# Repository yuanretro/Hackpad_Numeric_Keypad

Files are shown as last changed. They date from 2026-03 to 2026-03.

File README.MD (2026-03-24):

# HackPad: Numerical Keypad

By YuanRetro (William) Li, 2025.12 - 2026.3

Email: [admin@yuanshen.dev](mailto:admin@yuanshen.dev)

GitHub Repo: <https://github.com/yuanretro/Hackpad_Numeric_Keypad>

Last Revision: 2026-MAR-24

## Revision V4.0 2026-MAR-24

I edited the symbol in EasyEDA, so it now matches the diagram shown on SK6812 Mini-E's datasheet. This should solve the problem. 

The edit can be seen in the picture:

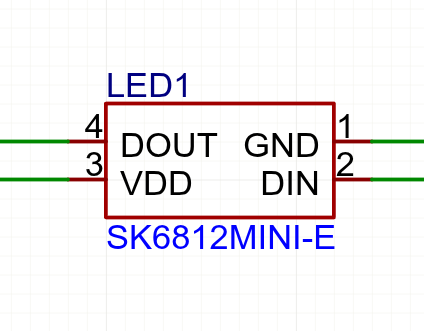
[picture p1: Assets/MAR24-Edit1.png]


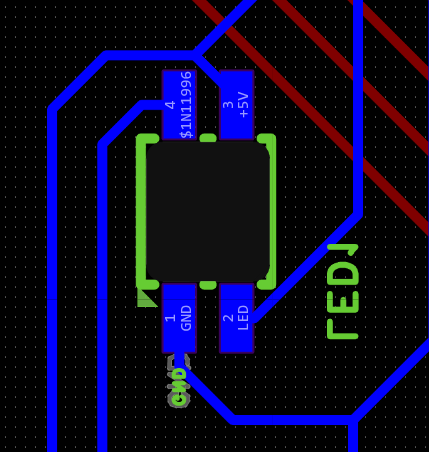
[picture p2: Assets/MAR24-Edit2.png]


## Revision V3.0 2026-MAR-23

I removed the button of the encoder from the matrix, and now the matrix is 4x4 instead of 5x4. The one extra GPIO is used to wire the encoder properly. Numlock can now be enabled by a long press of a certain key. The exact configuration is yet to be determined in the code. This edit also downsized the number of diodes required from 17 to 16.

## Revision V2.0 2026-MAR-22

The LED mounts are being relocated to the opposite side of the board and rewired. While I do know that the rotary encoder need one extra wire for proper directional detection, and I've thought of many ways to resolve this issue, including dropping the keypad to 15 keys. But to be honest, I believe that this would undermine the project's core purpose as a useful numerical keypad. Since the rotary encoder serves a secondary role in this application, not being able to detect the direction of rotation isn't really a big concern to me. Also, this can be compensated by allowing to flip the direction of the controls while pushing down the button during roration.

## Revision V1.0 2026-MAR-22

All issues stated are being dealt with. The keypad is downsized to 16 keys, and the push button of a rotary encoder replaces the NumLock key. As there isn't enough GPIO left for the encoder, I decided to only wire one output pin to the controller. This configuration only allows the detection of the distance of rotation and not the direction, but this can be partially resolved by detecting whether the switch is being pressed during rotation and alter the direction of the controls accordingly. (Don't worry about the one extra diode, I have spare components myself.)

The LEDs are being updated to the Mini-E variant of SK6812, and all diodes are now through-hole mount. Strangely enough, there seems to be some design issues with the package of the LEDs in EasyEDA. The slot region and the SMD pads are in minor conflict. This shouldn't affect anything despite of giving out nasty errors in the DRC check.

For the casing, I added 4 mounting holes on the corners, each measured around 2.8mm, allowing the screws to fit tightly inside the plastic and hold the two pieces together. An assembled view is also available down below.

The firmware haven't been updated, and I will do this step once the hardware part is complete.

## Introduction

This is my custom variant of [*HackPad*](https://github.com/hackclub/hackpad), an open-source keypad designed by *HackClub*. My project is loosely based on this, but I chose a different path for many elements of my design. Instead of only a few keys like the sample design, I incorporated a full-size computer numpad, very useful for small-size laptops that lack one. For many games I've played, especially simulation games like *Microsoft Flight Simulator* or *SimRail*, the numpad plays a crucial role in the controls, and it would be a pain to play them without one. 

For example, I used *EasyEDA* for the PCB design instead of *KiCAD*, as I have quite a lot of previous experience with it since I designed my first PCB back in 2023. It is also much easier to order PCBs right from the editor, and this makes the whole process less error-prone. I designed my 3D-printable shell initially with *Tinkercad*, but made use of *Autodesk Fusion* for the final touches. I have an Ender 3 V2 printer myself, and I will be able to print the whole casing myself. I am sure that the casing may not work on the first try, as I don't currently have the assembled PCB on hand. I will be able to do some minor tweaks once the PCB is up and running. Finally, instead of making use of the *QMK* firmware, I decided to write my own in C++ using the Arduino framework. I was able to compile it in the *PlatformIO* environment and export the .uf2 file, but I don't know if it works on the real hardware yet. This is also subject to minor changes.

I started working on this project in mid-December last year, but I was busy with school most of the time and almost forgot about it. This week, during March Break, I was able to pick it up and give it a finishing touch, and I hope the final product will work fine!

Honestly speaking, I think I am also much more confident with projects like this after I successfully completed the final performance task for my Computer Engineering course at school this January. For that project, called *Funnicator*, I designed a pair of text communication devices along with my partner, which use an ESP32-S3 microcontroller and sit in a custom 3D-printed case. Our teacher liked them. It was my first time designing 3D-printed items, and it helped me a lot when designing the case for my keypad, which is even more complicated.



## Schematics and PCB Design

As previously stated, I designed my PCB in EasyEDA. It is 10 cm by 10 cm exactly (this is somewhat important for minimizing the cost of the PCB, somehow), and I managed to fit a full-size arrangement of mechanical switches for a numpad. The keyboard matrix comes in a 4-row by 4-column arrangement, and takes up 8 GPIOs on the RP2040 microcontroller. Each individual switch is paired with a 1N4148 diode, to prevent current from flowing back and enable multiple keypresses at once. I used one extra GPIO for the 4 SK6812 LEDs forming a strip, and another one for one pin of the rotary encoder. The last two GPIOs went to the rotary encoder, which will act as an auxiliary control for my numpad.

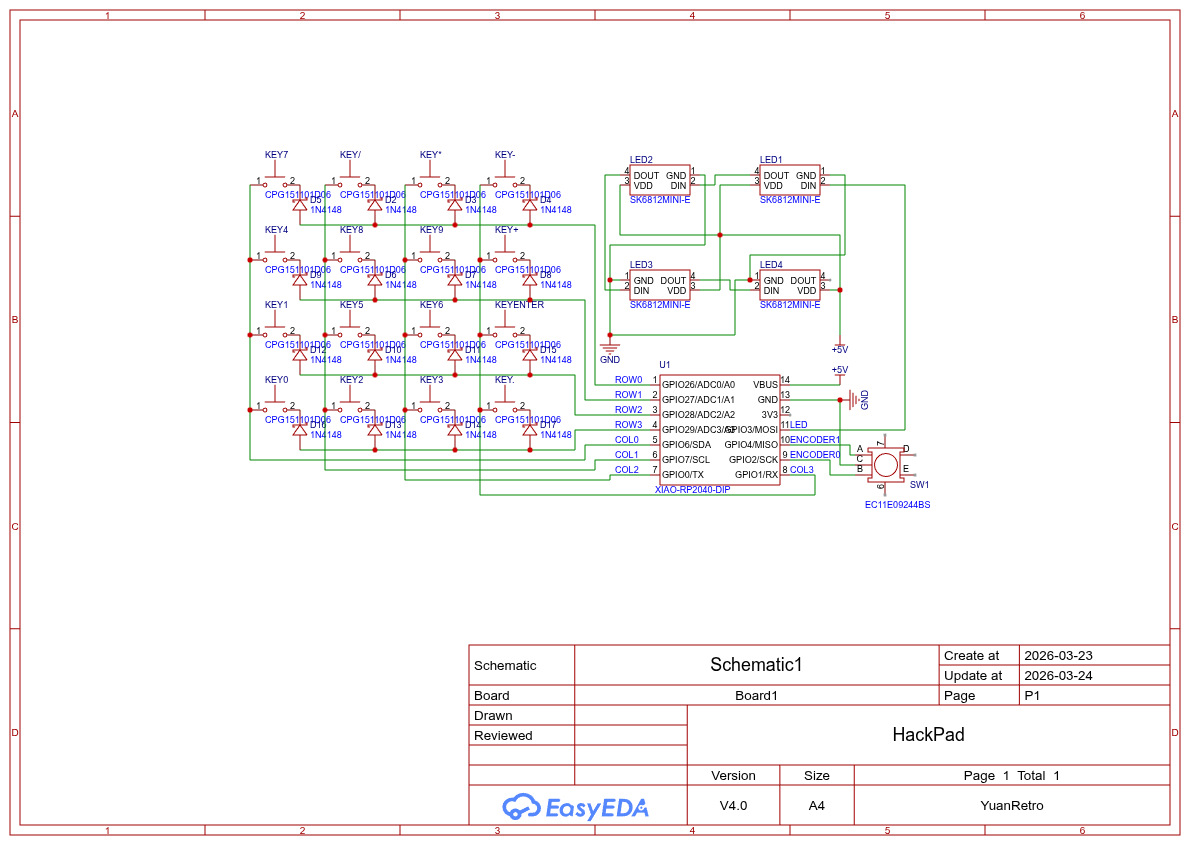
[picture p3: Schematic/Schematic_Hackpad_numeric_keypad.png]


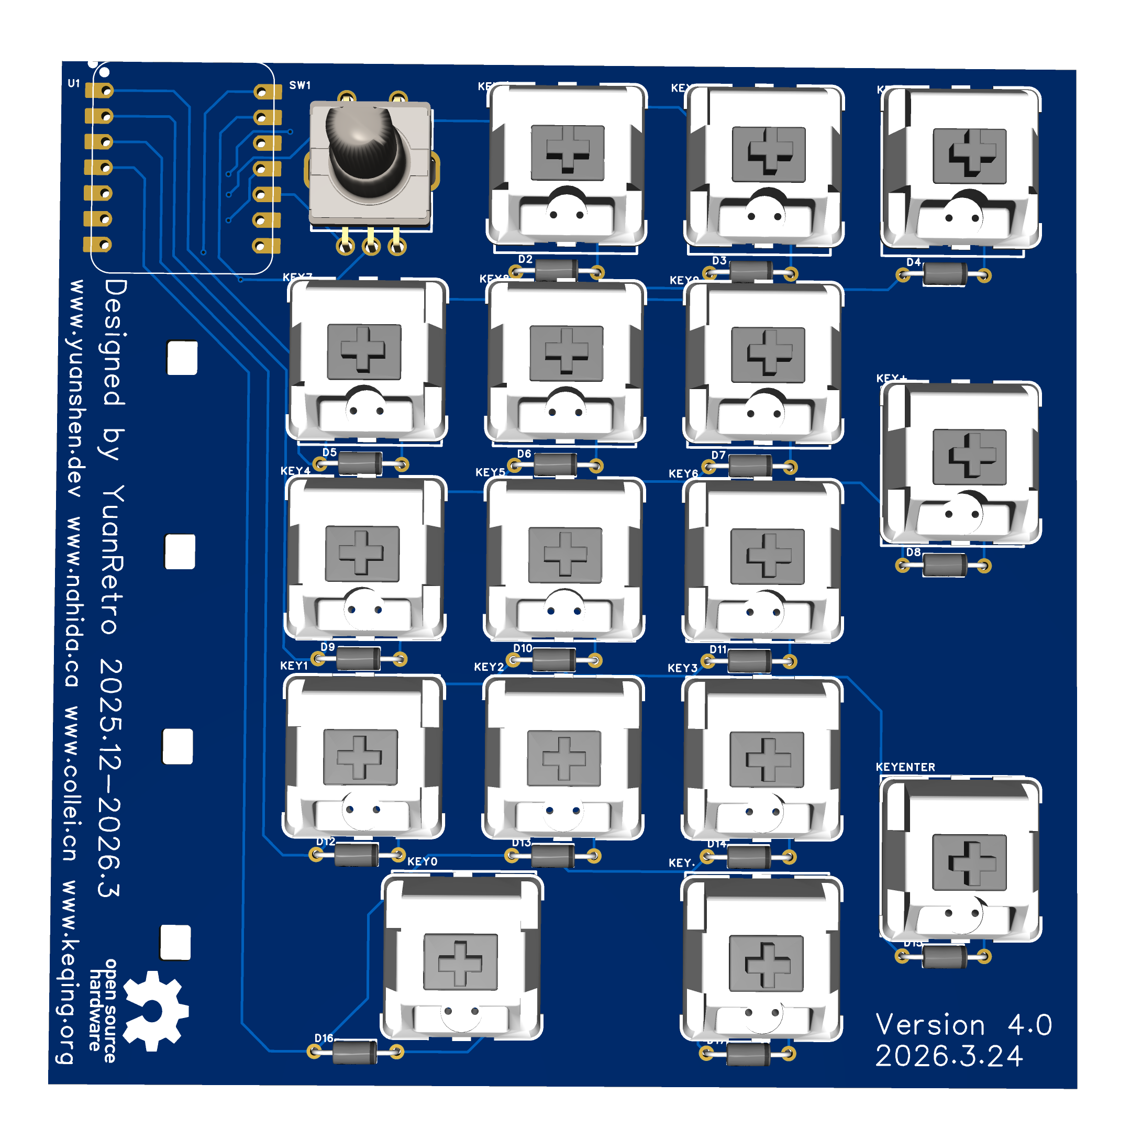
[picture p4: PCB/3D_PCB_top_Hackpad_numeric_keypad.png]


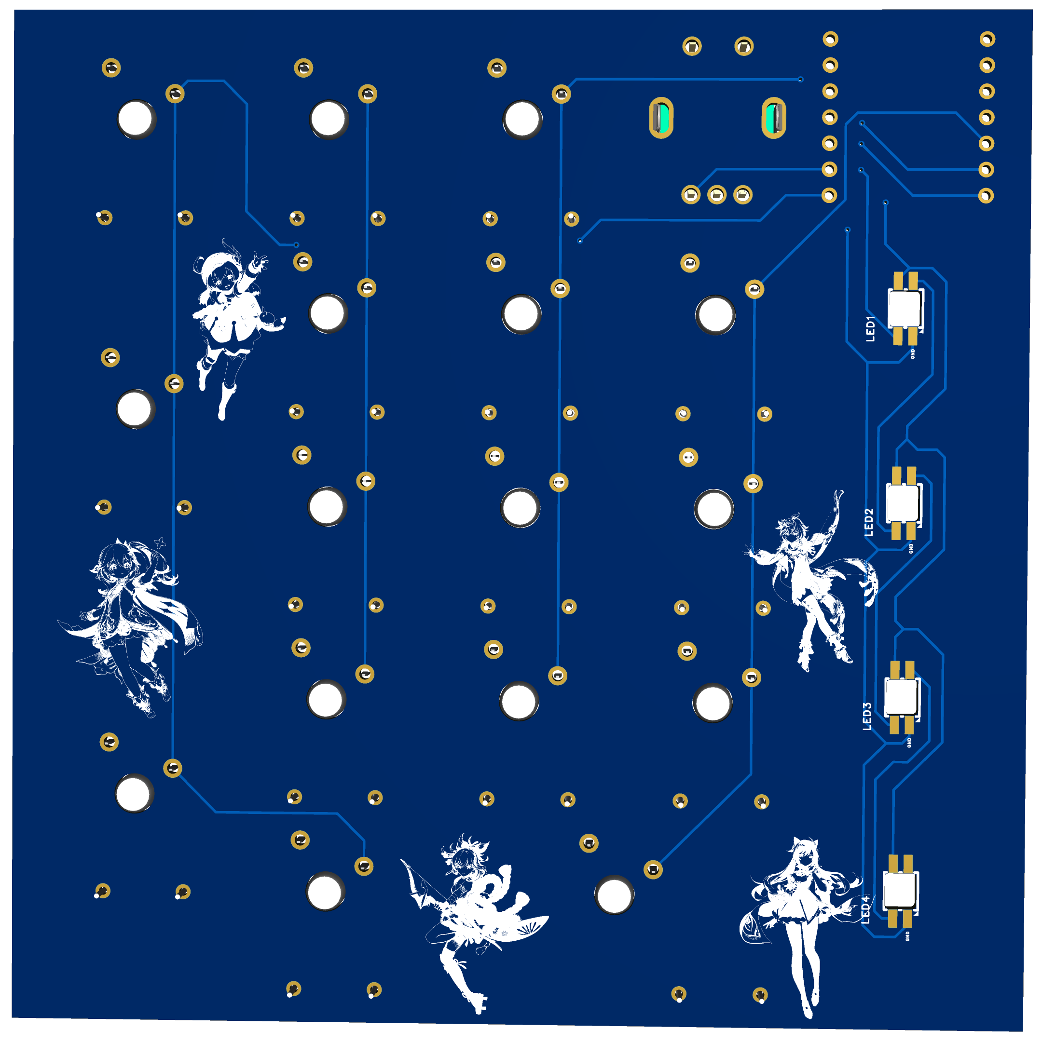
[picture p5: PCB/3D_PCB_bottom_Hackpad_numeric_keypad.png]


(clockwise from top-right: Collei, Keqing, Yoimiya, Nahida, and Klee)

## Parts Required

1 x Seeed Studio XIAO RP2040 Microcontroller

1 x EC11 Rotary Encoder

4 x SK6812 Mini-E Color LED

4 x M3 Screws of appropriate length (Supplied by myself)

16 x Standard Mechanical Key Switches

16 x Key Caps

16 x 1N4148 Diode

## Case Design

The case design is rather primitive, as I will definitely make some further tweaks once the PCB assembly is ready.  My idea for the casing is that it covers only the PCB and allows a small portion of the switch bodies to protrude above the case. This design can be found in many commercially available mechanical keyboards. It also comes with 4 2.8 mm mounting holes on the corners for screws to fit into.

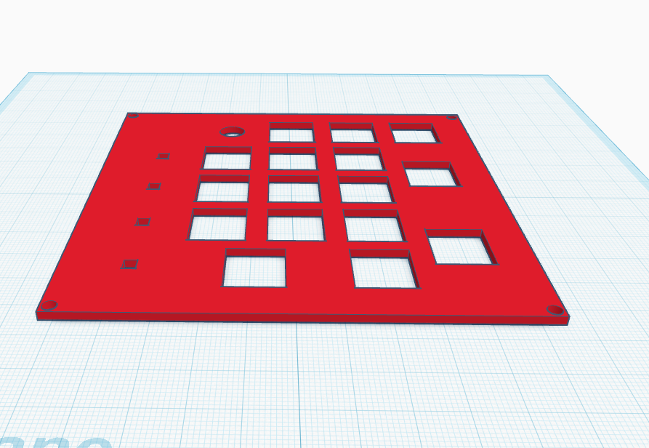
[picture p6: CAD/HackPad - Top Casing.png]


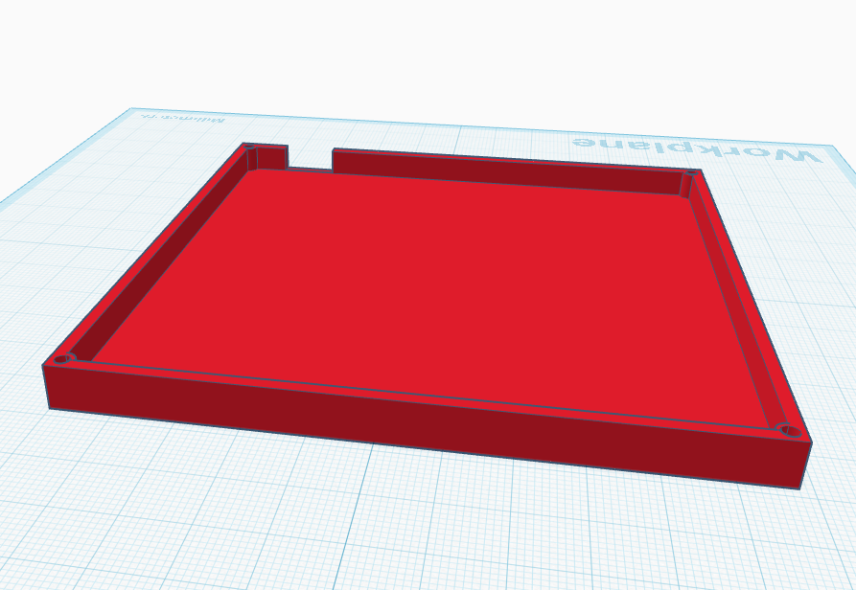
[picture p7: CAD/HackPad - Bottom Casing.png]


## Assembled View

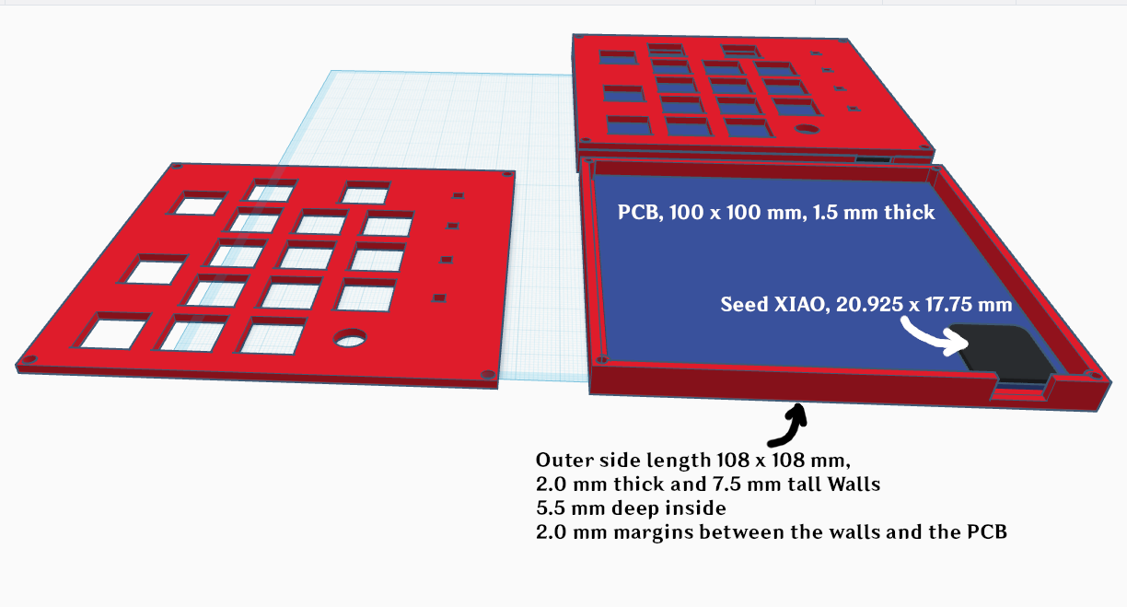
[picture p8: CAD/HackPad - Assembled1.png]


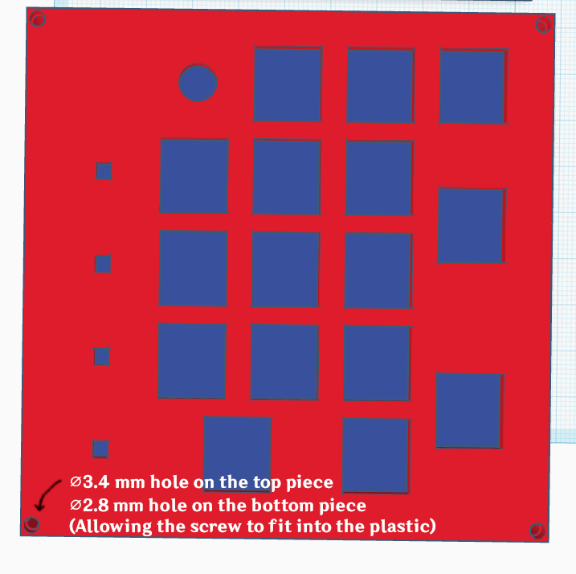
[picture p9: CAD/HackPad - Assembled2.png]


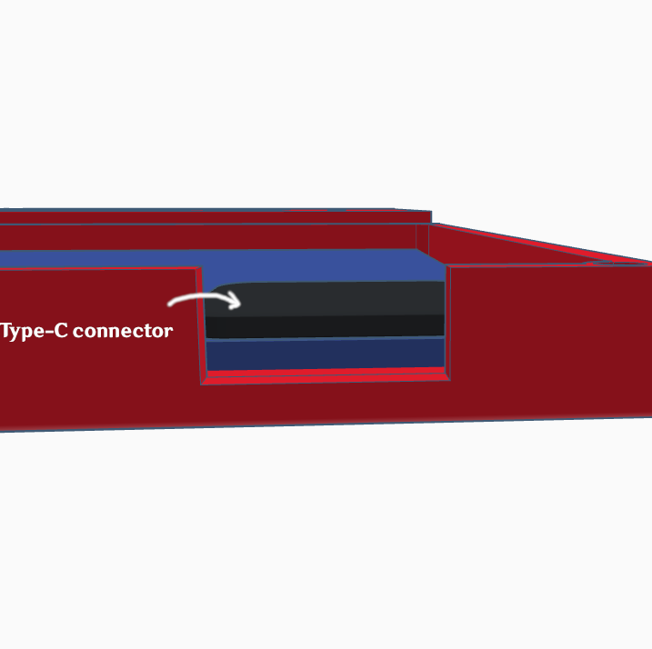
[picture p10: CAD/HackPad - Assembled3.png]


## Firmware

The firmware is written using the PlatformIO Arduino framework in C++. This can be changed at any time to fix bugs or add new features.

Current features of the firmware:

1. Registers the keypad as a standard USB HID device and sends inputs accordingly.

2. The NumLock key switches between number and function keys.

3. One of the LEDs in the strip indicates the current NumLock state, while the others flash on input.

4. The LED strip displays a breathing effect when the keypad is idle.

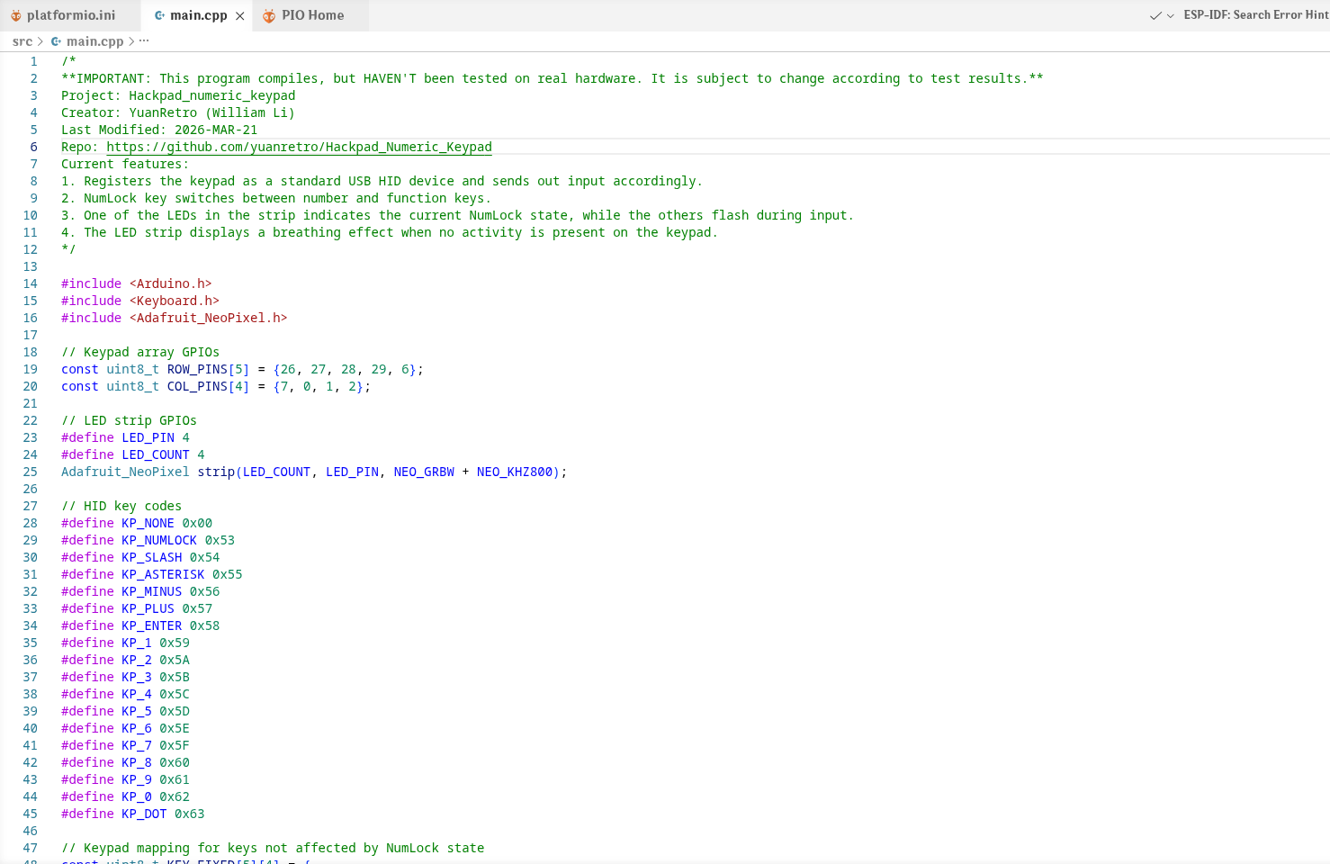
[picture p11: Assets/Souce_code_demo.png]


## Final Words

This project is rather novel to me, as it is my first time working with a RP2040 and USB HID devices. But it turned out easier than I originally thought it would be, and I hope it will work fine once everything is put together in the end!

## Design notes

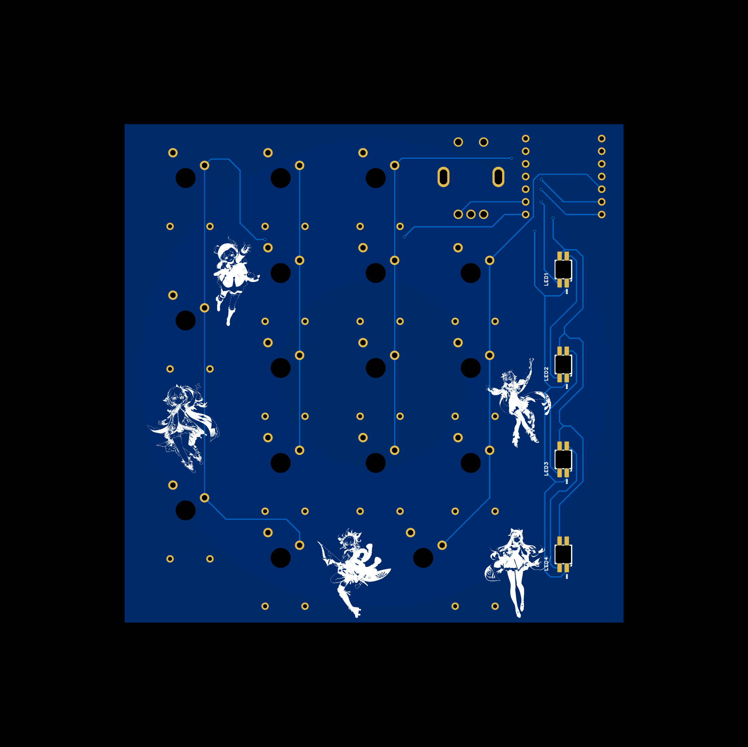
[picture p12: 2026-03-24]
PCB/2D_PCB_bottom_Hackpad_numeric_keypad.png

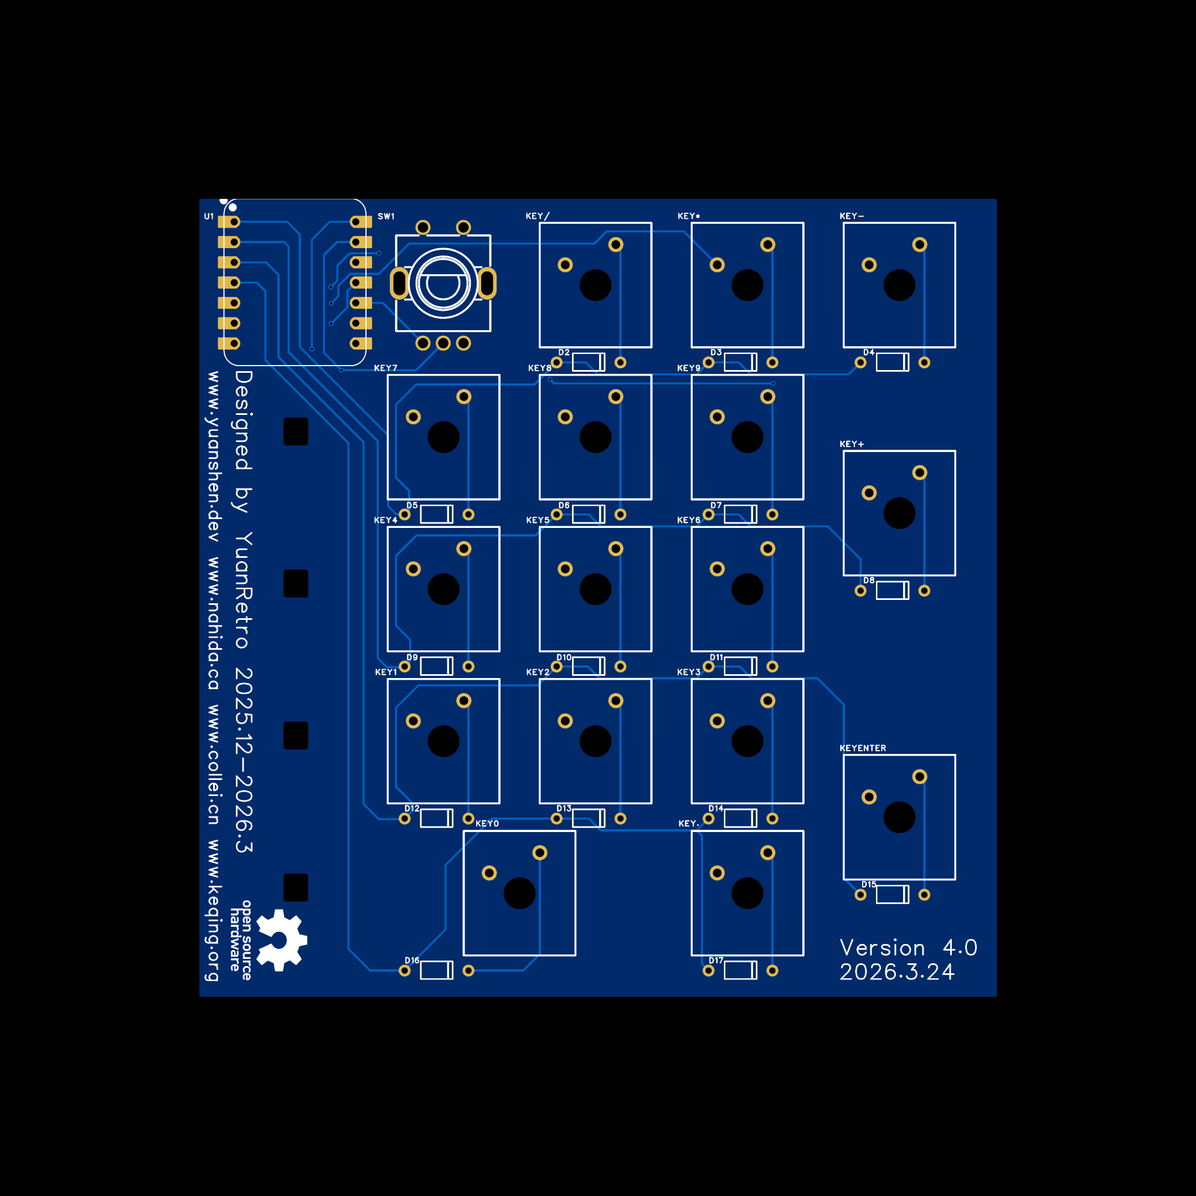
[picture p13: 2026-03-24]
PCB/2D_PCB_top_Hackpad_numeric_keypad.png

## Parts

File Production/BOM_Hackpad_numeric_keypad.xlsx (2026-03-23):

No. | Quantity | Comment | Designator | Footprint | Value | Manufacturer Part | Manufacturer | Supplier Part | Supplier
1 | 16 | 1N4148 | D2,D3,D4,D5,D6,D7,D8,D9,D10,D11,D12,D13,D14,D15,D16,D17 | DO-35_BD2.2-L4.0-D0.50_1N4148 |  | 1N4148 | LJ(朗捷) | C18195411 | LCSC
2 | 16 | CPG151101D06 | KEY0,KEY1,KEY2,KEY3,KEY4,KEY5,KEY6,KEY7,KEY8,KEY9,KEY*,KEY+,KEY-,KEY.,KEY/,KEYENTER | KEY-TH_CPG151101D06 |  | CPG151101D06 | HanElectricity(瀚源) | C49234237 | LCSC
3 | 4 | SK6812MINI-E | LED1,LED2,LED3,LED4 | LED-SMD_4P-L3.2-W2.8-LS5.9_SK6812MINI-E |  | SK6812MINI-E | 欧思科光电 | C5149201 | LCSC
4 | 1 | EC11E09244BS | SW1 | SW-TH_EC11XXXXXXXX |  | EC11E09244BS | ALPSALPINE(阿尔卑斯阿尔派) | C470742 | LCSC
5 | 1 | XIAO-RP2040-DIP | U1 | XIAO-RP2040-DIP

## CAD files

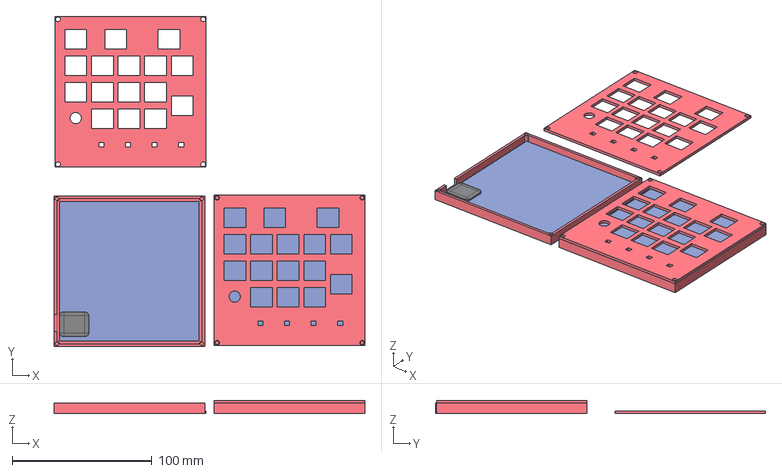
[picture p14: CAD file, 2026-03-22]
CAD/HackPad - Assembled.step
222.8 x 236.5 x 9.50 mm

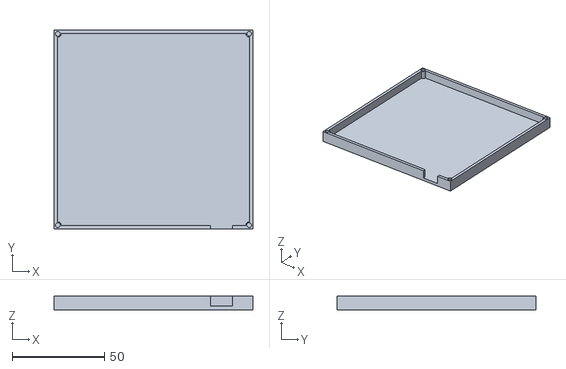
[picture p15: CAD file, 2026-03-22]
Production/Print_HackPad_Bottom Casing.stl
108.0 x 108.0 x 7.50

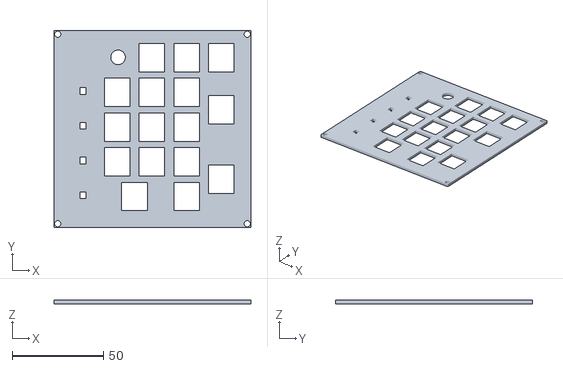
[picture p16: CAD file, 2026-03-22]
Production/Print_HackPad_Top Casing.stl
108.0 x 108.0 x 2.00

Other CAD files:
CAD/HackPad - Bottom Casing.step
CAD/HackPad - Top Casing.step
CAD/HackPad - Assembled.f3d
CAD/HackPad - Bottom Casing.f3d
CAD/HackPad - Top Casing.f3d

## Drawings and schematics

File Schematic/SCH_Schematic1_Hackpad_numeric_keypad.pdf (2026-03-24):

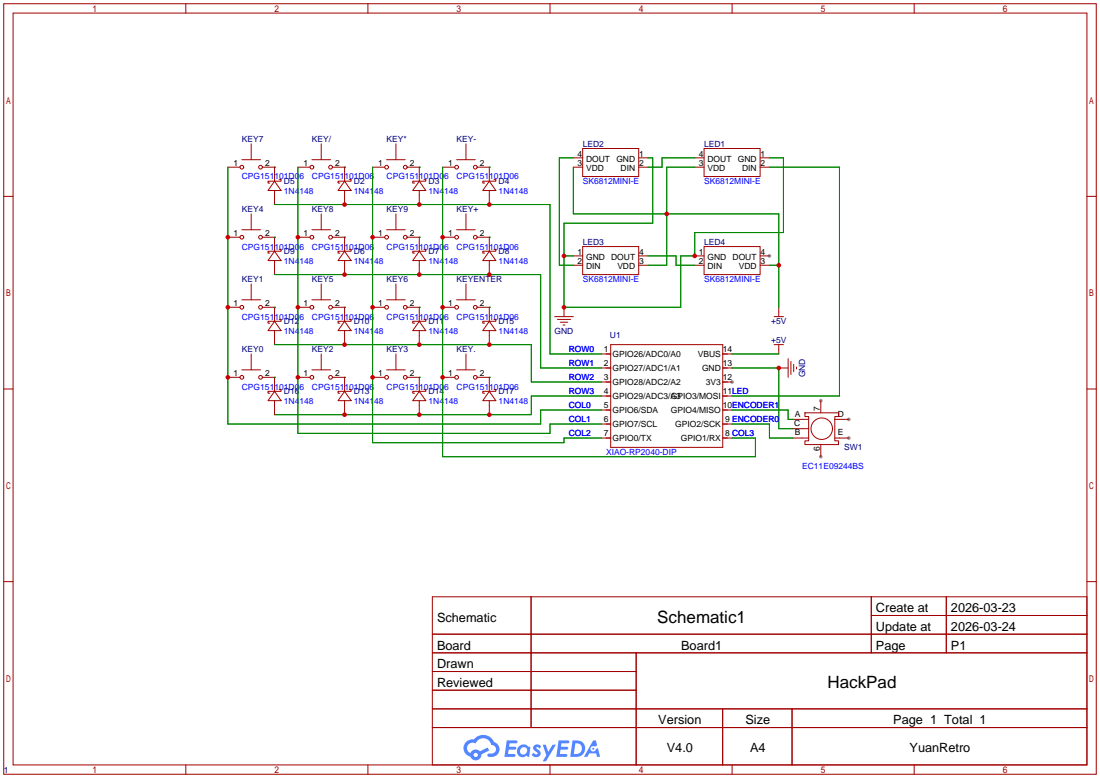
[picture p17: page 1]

D9 1N4148 | KEY8 1 2 CPG151101D06 | D6 1N4148 | KEY9 1 2 | D7 1N4148 | KEY+ 1 2 CPG151101D06 | D8 1N4148

D12 1N4148 | KEY5 1 2 CPG151101D06 | D10 1N4148 | KEY6 1 2 | D11 1N4148 | KEYENTER 1 2 CPG151101D06 | D15 1N4148

COL0 | GPIO6/SDA 5 | ENCODER1
COL1 | GPIO7/SCL 6 | ENCODER0

Schematic | Schematic1 | Create at | 2026-03-23

Update at | 2026-03-24

Board | Board1 | Page | P1
Drawn | | HackPad
Reviewed

Version | Size | Page 1 Total 1
V4.0 | A4 | YuanRetro

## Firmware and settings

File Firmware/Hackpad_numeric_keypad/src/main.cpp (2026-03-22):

/*
**IMPORTANT: This program compiles, but HAVEN'T been tested on real hardware. It is subject to change according to test results.**
Project: Hackpad_numeric_keypad
Creator: YuanRetro (William Li)
Last Modified: 2026-MAR-21
Repo: https://github.com/yuanretro/Hackpad_Numeric_Keypad
Current features:
- Registers the keypad as a standard USB HID device and sends inputs accordingly.
- The NumLock key switches between number and function keys.
- One of the LEDs in the strip indicates the current NumLock state, while the others flash on input.
- The LED strip displays a breathing effect when the keypad is idle.
*/

#include <Arduino.h>
#include <Keyboard.h>
#include <Adafruit_NeoPixel.h>

// Keypad array GPIOs
const uint8_t ROW_PINS[5] = {26, 27, 28, 29, 6};
const uint8_t COL_PINS[4] = {7, 0, 1, 2};

// LED strip GPIOs
#define LED_PIN 4
#define LED_COUNT 4
Adafruit_NeoPixel strip(LED_COUNT, LED_PIN, NEO_GRBW + NEO_KHZ800);

// HID key codes
#define KP_NONE 0x00
#define KP_NUMLOCK 0x53
#define KP_SLASH 0x54
#define KP_ASTERISK 0x55
#define KP_MINUS 0x56
#define KP_PLUS 0x57
#define KP_ENTER 0x58
#define KP_1 0x59
#define KP_2 0x5A
#define KP_3 0x5B
#define KP_4 0x5C
#define KP_5 0x5D
#define KP_6 0x5E
#define KP_7 0x5F
#define KP_8 0x60
#define KP_9 0x61
#define KP_0 0x62
#define KP_DOT 0x63

// Keypad mapping for keys not affected by NumLock state
const uint8_t KEY_FIXED[5][4] = {
    {KP_NUMLOCK, KP_SLASH, KP_ASTERISK, KP_MINUS},
    {KP_NONE, KP_NONE, KP_NONE, KP_PLUS},
    {KP_NONE, KP_NONE, KP_NONE, KP_NONE},
    {KP_NONE, KP_NONE, KP_NONE, KP_ENTER},
    {KP_NONE, KP_NONE, KP_NONE, KP_NONE},
};

// Keypad mapping when NumLock is active
const uint8_t KEY_NUMON[5][4] = {
    {KP_NONE, KP_NONE, KP_NONE, KP_NONE},
    {KP_7, KP_8, KP_9, KP_NONE},
    {KP_4, KP_5, KP_6, KP_NONE},
    {KP_1, KP_2, KP_3, KP_NONE},
    {KP_0, KP_NONE, KP_DOT, KP_NONE},
};

// Keypad mapping when NumLock is inactive
const uint8_t KEY_NUMOFF[5][4] = {
    {KP_NONE, KP_NONE, KP_NONE, KP_NONE},
    {KEY_HOME, KEY_UP_ARROW, KEY_PAGE_UP, KP_NONE},
    {KEY_LEFT_ARROW, KP_NONE, KEY_RIGHT_ARROW, KP_NONE},
    {KEY_END, KEY_DOWN_ARROW, KEY_PAGE_DOWN, KP_NONE},
    {KEY_INSERT, KP_NONE, KEY_DELETE, KP_NONE},
};

// Key states
bool keyState[5][4] = {};
uint32_t lastChange[5][4] = {};
const uint32_t DEBOUNCE_MS = 12;

// NumLock state
bool numLock = true;
uint8_t colPressed[4] = {};

uint32_t COL_COLOR[4];

// Initial colors for the LED strip
void initColors()
{
  COL_COLOR[0] = strip.Color(180, 0, 255, 0);
  COL_COLOR[1] = strip.Color(255, 0, 80, 0);
  COL_COLOR[2] = strip.Color(60, 200, 255, 0);
  COL_COLOR[3] = strip.Color(140, 255, 0, 0);
}

// Update LED strip according to key press
void updateLEDs()
{
  for (int c = 0; c < 4; c++)
  {
    if (colPressed[c] > 0)
    {
      strip.setPixelColor(c, COL_COLOR[c]);
    }
    else if (c == 0 && numLock)
    {
      strip.setPixelColor(c, strip.Color(0, 0, 0, 50));
    }
    else
    {
      strip.setPixelColor(c, strip.Color(0, 0, 5, 8));
    }
  }
  strip.show();
}

// Breathe effect when no activity is present
void breathe()
{
  static uint32_t lastT = 0;
  static float phase = 0;
  if (millis() - lastT < 16)
    return;
  lastT = millis();
  phase += 0.02f;
  uint8_t w = (uint8_t)(25 + 25 * sinf(phase));
  strip.setPixelColor(0, strip.Color(0, 0, 0, numLock ? 50 : w));
  for (int i = 1; i < LED_COUNT; i++)
  {
    strip.setPixelColor(i, strip.Color(0, 0, w / 4, w));
  }
  strip.show();
}

// Obtain respective key code when a key is pressed
uint8_t getKeycode(int r, int c)
{
  if (KEY_FIXED[r][c] != KP_NONE)
  {
    return KEY_FIXED[r][c];
  }
  else
  {
    return numLock ? KEY_NUMON[r][c] : KEY_NUMOFF[r][c];
  }
}

// Initial setup method, executed each time the microcontroller boots
void setup()
{
  // Set up keyboard scanning
  for (int r = 0; r < 5; r++)
  {
    pinMode(ROW_PINS[r], OUTPUT);
    digitalWrite(ROW_PINS[r], HIGH);
  }
  for (int c = 0; c < 4; c++)
  {
    pinMode(COL_PINS[c], INPUT_PULLUP);
  }

  Keyboard.begin();

  // Set up LED strip
  strip.begin();
  strip.setBrightness(90);
  strip.clear();
  strip.show();

  initColors();
  updateLEDs();
}

// Executes repeatedly as long as the keypad is plugged in
void loop()
{
  bool anyPressed = false;
  bool ledDirty = false;

  // Scan for key presses
  for (int r = 0; r < 5; r++)
  {
    digitalWrite(ROW_PINS[r], LOW);
    delayMicroseconds(10);

    for (int c = 0; c < 4; c++)
    {
      // Ignore unrecognized keys
      uint8_t kc = getKeycode(r, c);
      if (kc == KP_NONE)
        continue;

      bool reading = !digitalRead(COL_PINS[c]);

      // Debouncing
      if (reading != keyState[r][c])
      {
        if (millis() - lastChange[r][c] >= DEBOUNCE_MS)
        {
          lastChange[r][c] = millis();
          keyState[r][c] = reading;

          if (reading)
          {
            if (kc == KP_NUMLOCK)
              numLock = !numLock;
            Keyboard.press(kc);
            colPressed[c]++;
          }
          else
          {
            Keyboard.release(kc);
            if (colPressed[c] > 0)
              colPressed[c]--;
          }
          ledDirty = true;
        }
      }
      if (keyState[r][c])
        anyPressed = true;
    }

    digitalWrite(ROW_PINS[r], HIGH);
  }

  // Start breathing once no activity is detected
  if (ledDirty)
  {
    updateLEDs();
  }
  else if (!anyPressed)
  {
    breathe();
  }

  delay(1);
}

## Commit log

2026-03-21 Uploaded PCB and Case designs
    [HackPad - Bottom Casing.f3z, HackPad - Bottom Casing.step, HackPad - Top Casing.f3z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]
2026-03-21 Added BOM
    [BOM_Hackpad_numeric_keypad.xlsx]
2026-03-22 Revision, resolved numerous issues
    [BOM_Hackpad_numeric_keypad.xlsx, HackPad - Assembled.f3d, HackPad - Assembled.step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]
2026-03-23 Updated PCB
2026-03-23 Updated PCB design
    [BOM_Hackpad_numeric_keypad.xlsx]
